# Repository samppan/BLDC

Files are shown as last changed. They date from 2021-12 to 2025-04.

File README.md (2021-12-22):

# BLDC

## BLDC Motor Driver Architecture
3 key building blocks for BLDC motor driver are: 
1. Motor controller, typically a MCU
2. Gate Drivers; PWM input, output drives half-bridges
3. Power MOSFET in half-bridges
4. Senseored feedback
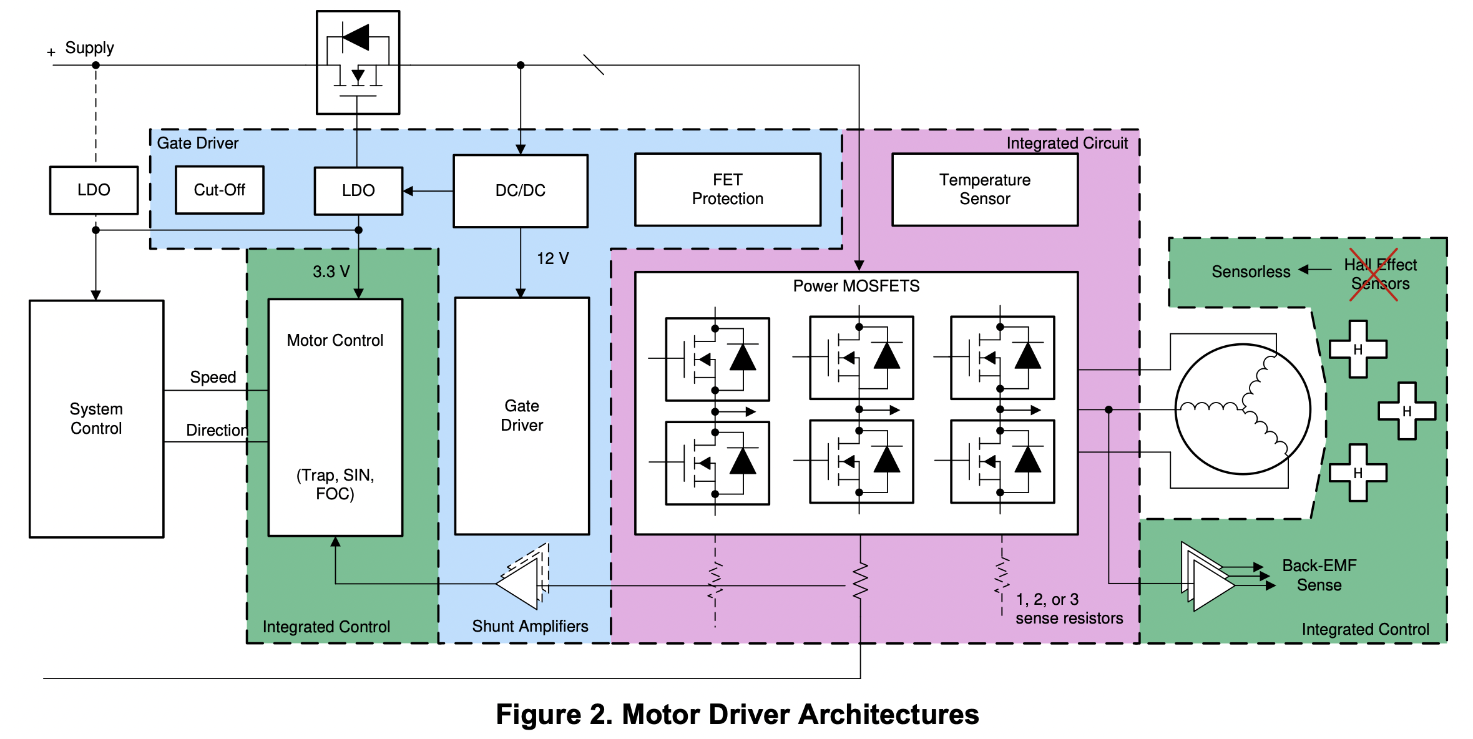
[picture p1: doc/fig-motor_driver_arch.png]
Source: TI

<figcaption>Source: TI</figcaption>

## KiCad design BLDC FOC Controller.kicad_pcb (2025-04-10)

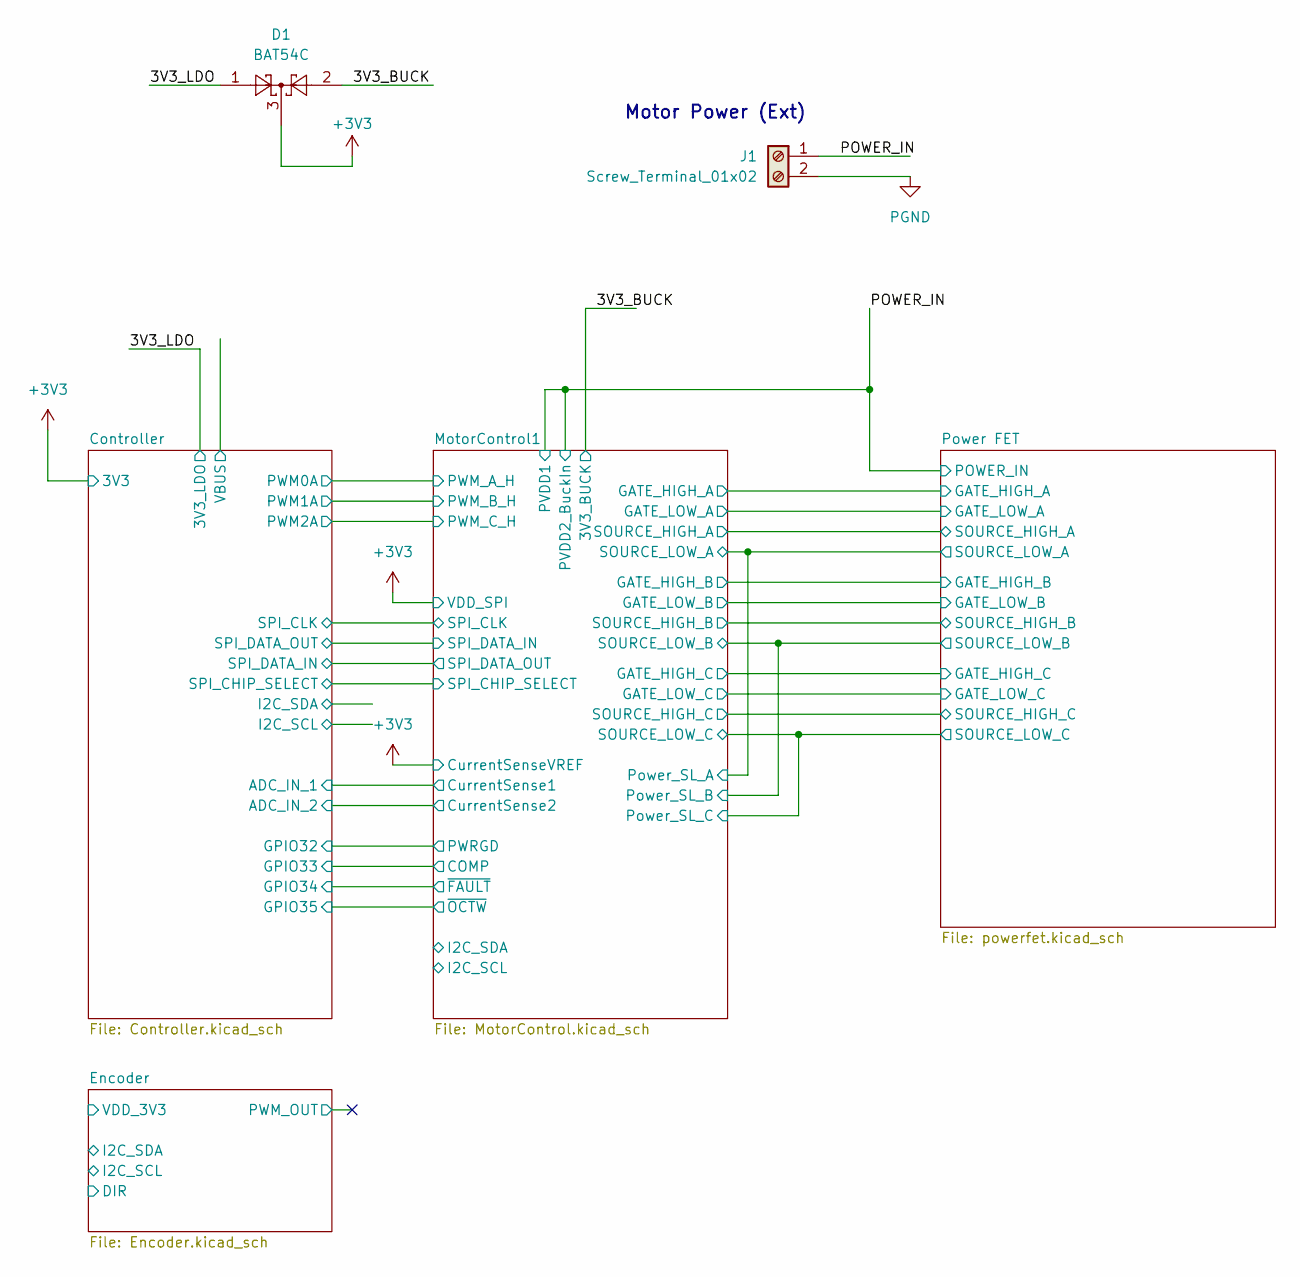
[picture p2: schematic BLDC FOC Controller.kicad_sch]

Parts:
D1: BAT54C; SOT-23
J1: Screw_Terminal_01x02; TerminalBlock_TE_282834-2_1x02_P2.54mm_Horizontal

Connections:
/3V3_BUCK: D1.2; also elsewhere on the board
/3V3_LDO: D1.1; also elsewhere on the board
/POWER_IN: J1.1; also elsewhere on the board
GNDA: J1.2; also elsewhere on the board

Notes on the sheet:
Motor Power (Ext)

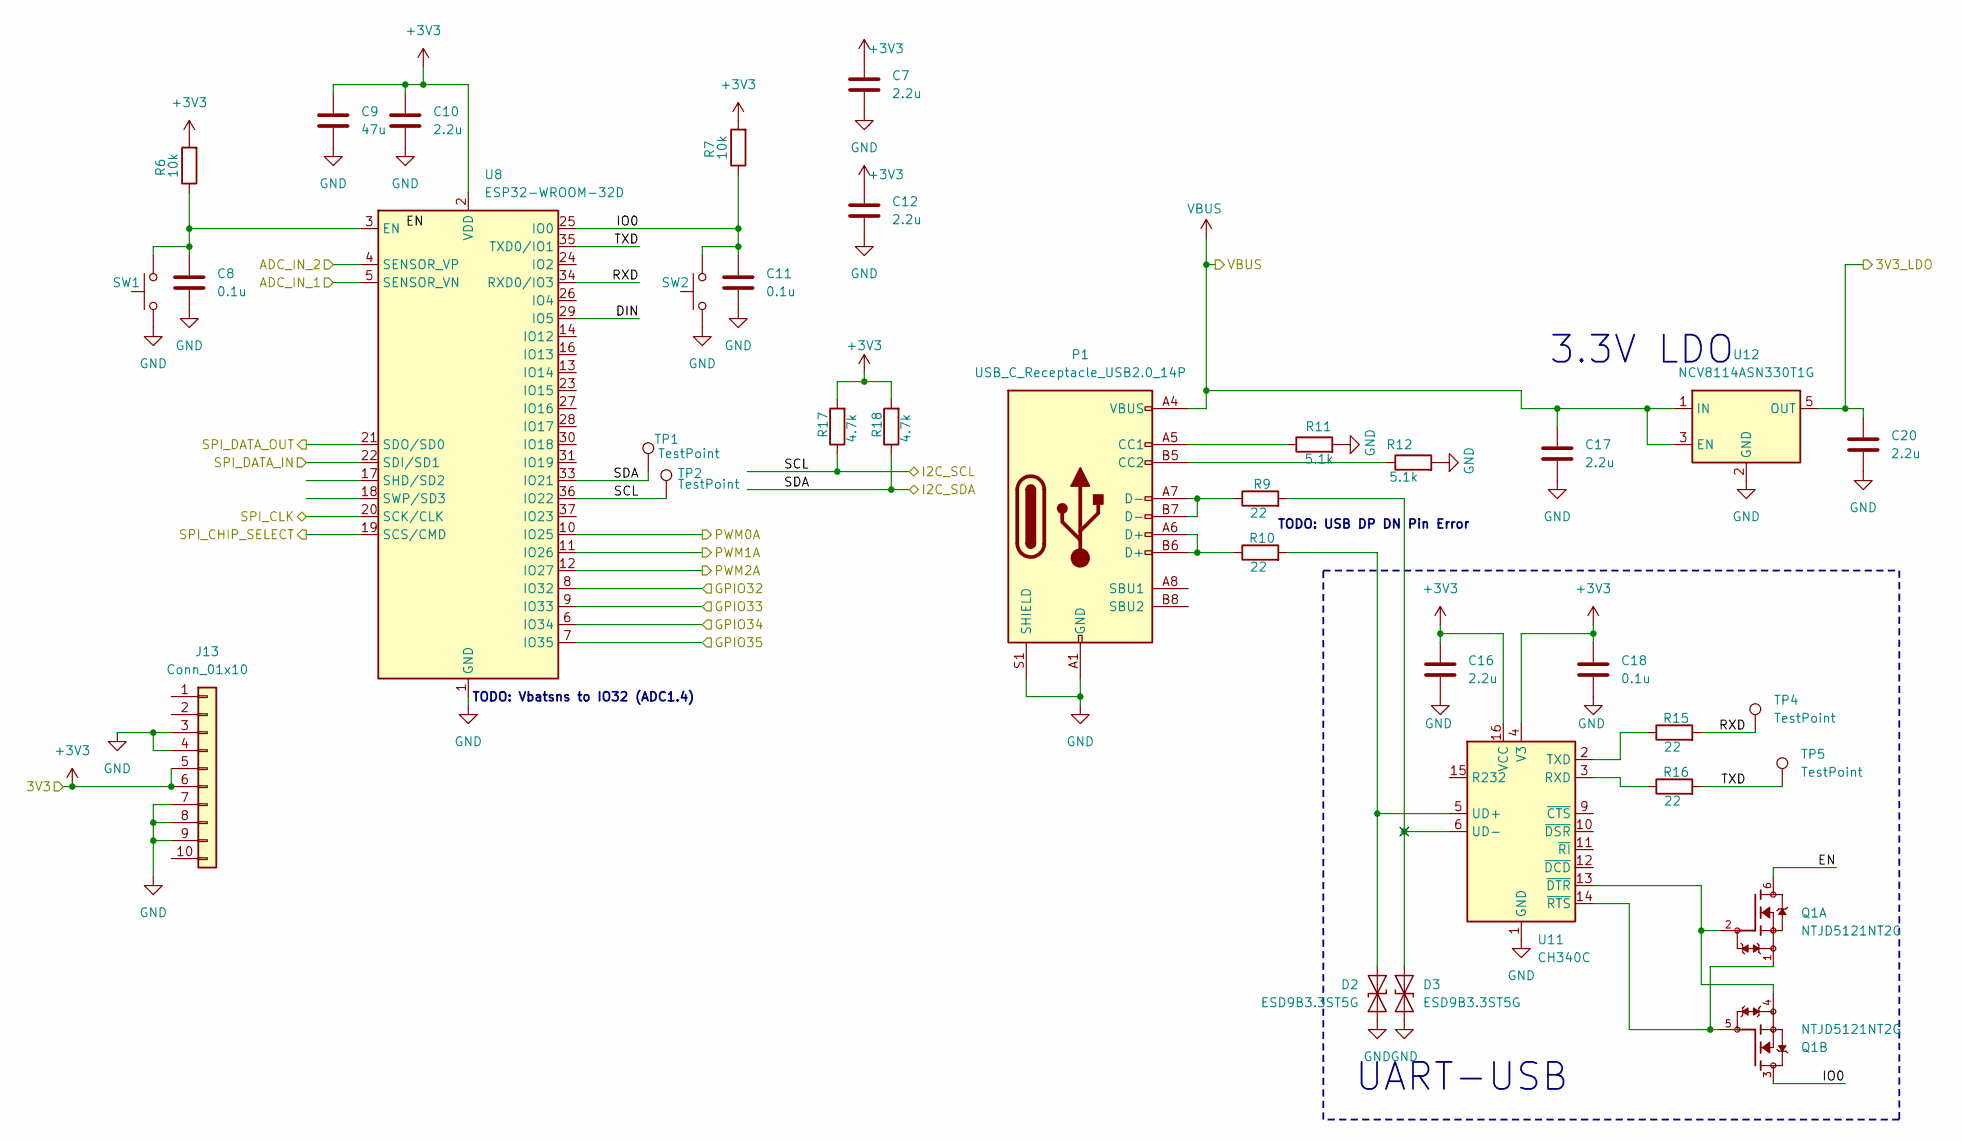
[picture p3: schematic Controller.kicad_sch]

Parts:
C7, C10, C12, C16, C17, C20: 2.2u; C_0603_1608Metric_Pad1.08x0.95mm_HandSolder
C8, C11, C18: 0.1u; C_0603_1608Metric_Pad1.08x0.95mm_HandSolder
C9: 47u; C_1206_3216Metric_Pad1.33x1.80mm_HandSolder
D2, D3: ESD9B3.3ST5G; D_SOD-923
J13: Conn_01x10; PinSocket_1x10_P2.54mm_Vertical
P1: USB_C_Receptacle_USB2.0_14P; USB_C_Receptacle_JAE_DX07S016JA1R1500
Q1: NTJD5121NT2G; SOT65P210X110-6N; PARTREV 9
R6, R7: 10k; R_0603_1608Metric_Pad0.98x0.95mm_HandSolder
R9, R10, R15, R16: 22; R_0603_1608Metric_Pad0.98x0.95mm_HandSolder
R11, R12: 5.1k; R_0603_1608Metric_Pad0.98x0.95mm_HandSolder
R17, R18: 4.7k; R_0603_1608Metric_Pad0.98x0.95mm_HandSolder
SW1, SW2: SW_Push_SPST_NO_Alps_SKRK
TP1, TP2, TP4, TP5: TestPoint; TestPoint_Pad_D1.5mm
U8: ESP32-WROOM-32D
U11: CH340C; SOIC-16_3.9x9.9mm_P1.27mm
U12: NCV8114ASN330T1G; TSOT-23-5

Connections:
/3V3_LDO: C20.1, U12.5 (OUT); also elsewhere on the board
/Controller/DIN: U8.29 (IO5)
/Controller/IO0: C11.1, Q1.3, R7.1, SW2.2, U8.25 (IO0)
/Controller/RXD: R15.2, TP4.1, U8.34 (RXD0/IO3)
/Controller/SCL: R17.1, TP2.1, U8.36 (IO22)
/Controller/SDA: R18.1, TP1.1, U8.33 (IO21)
/Controller/TXD: R16.2, TP5.1, U8.35 (TXD0/IO1)
/MotorControl1/COMP: U8.9 (IO33); also elsewhere on the board
/MotorControl1/INH_A: U8.10 (IO25); also elsewhere on the board
/MotorControl1/INH_B: U8.11 (IO26); also elsewhere on the board
/MotorControl1/INH_C: U8.12 (IO27); also elsewhere on the board
/MotorControl1/PWRGD: U8.8 (IO32); also elsewhere on the board
/MotorControl1/SCLK: U8.20 (SCK/CLK); also elsewhere on the board
/MotorControl1/SDI: U8.21 (SDO/SD0); also elsewhere on the board
/MotorControl1/SDO: U8.22 (SDI/SD1); also elsewhere on the board
/MotorControl1/SO1: U8.5 (SENSOR_VN); also elsewhere on the board
/MotorControl1/SO2: U8.4 (SENSOR_VP); also elsewhere on the board
/MotorControl1/~FAULT: U8.6 (IO34); also elsewhere on the board
/MotorControl1/~OCTW: U8.7 (IO35); also elsewhere on the board
/MotorControl1/~SCS: U8.19 (SCS/CMD); also elsewhere on the board
GND: C7.2, C8.2, C9.2, C10.2, C11.2, C12.2, C16.2, C17.2, C18.2, C20.2, D2.1 (A1), D3.1 (A1), J13.3, J13.4, J13.7, J13.8, J13.9, P1.A1 (GND), P1.A12 (GND), P1.B1 (GND), P1.B12 (GND), P1.S1 (SHIELD), R11.2, R12.2, SW1.1, SW2.1, U8.1 (GND), U8.15 (GND), U8.38 (GND), U8.39 (GND), U11.1 (GND), U12.2 (GND); also elsewhere on the board
unnamed: D2.2 (A2), R10.2, U11.5 (UD+)
unnamed: P1.A5 (CC1), R11.1
unnamed: P1.B5 (CC2), R12.1
unnamed: P1.A6 (D+), P1.B6 (D+), R10.1
unnamed: P1.A7 (D-), P1.B7 (D-), R9.1
unnamed: C8.1, R6.1, SW1.2, U8.3 (EN)
unnamed: R16.1, U11.3 (RXD)
unnamed: R15.1, U11.2 (TXD)
unnamed: Q1.2, Q1.4, U11.13 (~DTR)
unnamed: Q1.1, Q1.5, U11.14 (~RTS)
VBUS: C17.1, P1.A4 (VBUS), P1.A9 (VBUS), P1.B4 (VBUS), P1.B9 (VBUS), U12.1 (IN), U12.3 (EN)

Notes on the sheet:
UART-USB
3.3V LDO
TODO: Vbatsns to IO32 (ADC1.4)
TODO: USB DP DN Pin Error

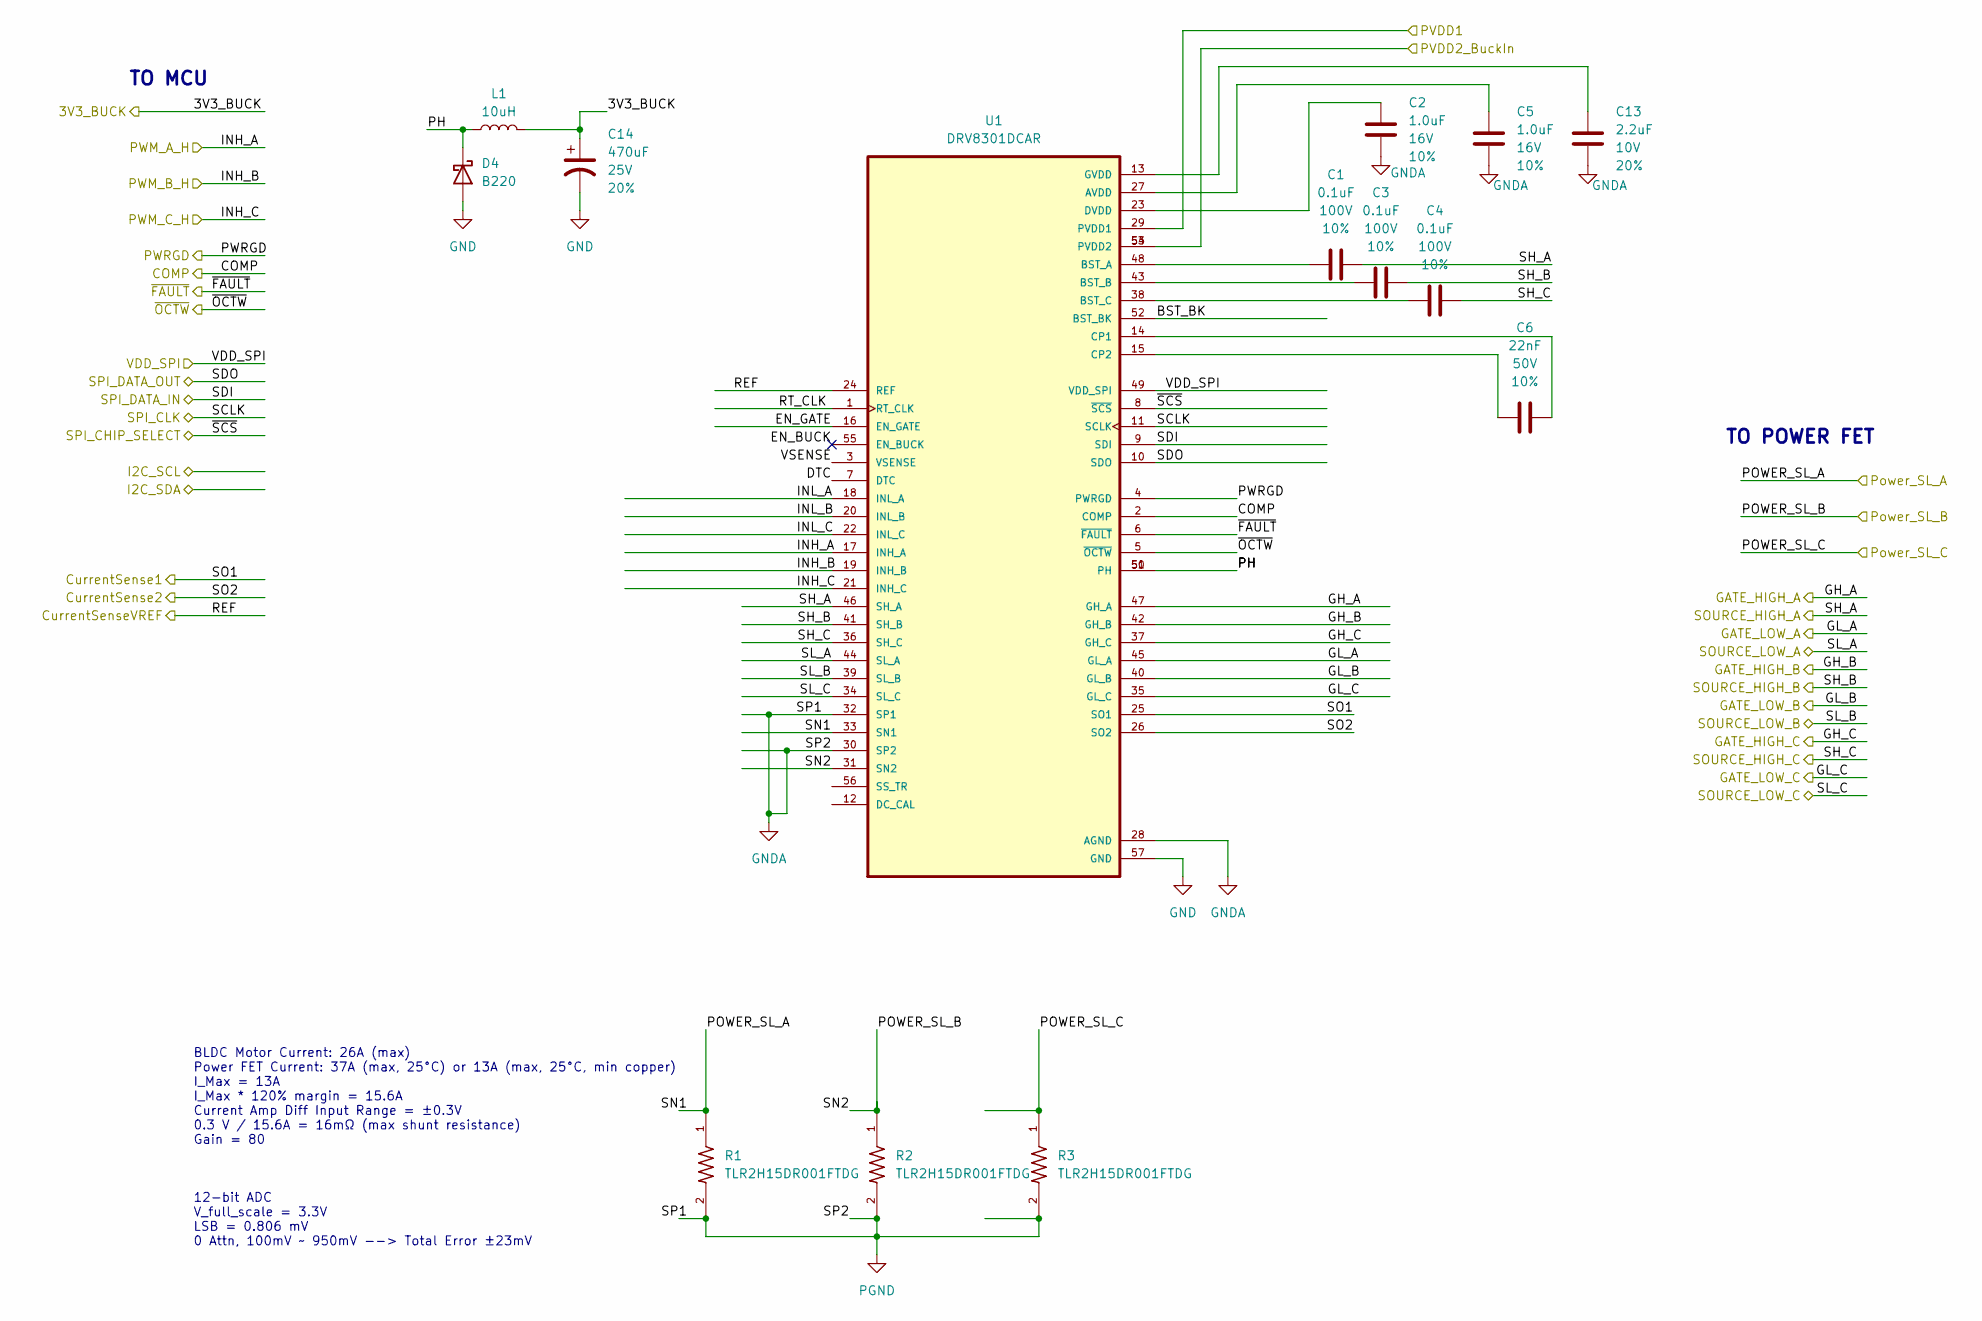
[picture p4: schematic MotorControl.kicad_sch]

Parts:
C1, C3, C4: 0.1uF; C_0603_1608Metric; Voltage 100V; Tolerance 10%
C2, C5: 1.0uF; C_0603_1608Metric; Voltage 16V; Tolerance 10%
C6: 22nF; C_0603_1608Metric; Voltage 50V; Tolerance 10%
C13: 2.2uF; C_0603_1608Metric_Pad1.08x0.95mm_HandSolder; Voltage 10V; Tolerance 20%
C14: 470uF; CP_Elec_10x10; Voltage 25V; Tolerance 20%
D4: B220; D_SMB
L1: 10uH; L_Taiyo-Yuden_NR-50xx_HandSoldering
R1, R2, R3: TLR2H15DR001FTDG; RESC5025X70N; Tolerance 1%
U1: DRV8301DCAR; HTSSOP-56-1EP_6.1x14mm_P0.5mm_EP3.61x6.35mm; PARTREV F

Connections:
/3V3_BUCK: C14.1, L1.2; also elsewhere on the board
/MotorControl1/BST_BK: U1.52 (BST_BK)
/MotorControl1/COMP: U1.2 (COMP); also elsewhere on the board
/MotorControl1/DTC: U1.7 (DTC)
/MotorControl1/EN_BUCK: U1.55 (EN_BUCK)
/MotorControl1/EN_GATE: U1.16 (EN_GATE)
/MotorControl1/GH_A: U1.47 (GH_A); also elsewhere on the board
/MotorControl1/GH_B: U1.42 (GH_B); also elsewhere on the board
/MotorControl1/GH_C: U1.37 (GH_C); also elsewhere on the board
/MotorControl1/GL_A: U1.45 (GL_A); also elsewhere on the board
/MotorControl1/GL_B: U1.40 (GL_B); also elsewhere on the board
/MotorControl1/GL_C: U1.35 (GL_C); also elsewhere on the board
/MotorControl1/INH_A: U1.17 (INH_A); also elsewhere on the board
/MotorControl1/INH_B: U1.19 (INH_B); also elsewhere on the board
/MotorControl1/INH_C: U1.21 (INH_C); also elsewhere on the board
/MotorControl1/INL_A: U1.18 (INL_A)
/MotorControl1/INL_B: U1.20 (INL_B)
/MotorControl1/INL_C: U1.22 (INL_C)
/MotorControl1/PH: D4.1 (K), L1.1, U1.50 (PH), U1.51 (PH)
/MotorControl1/POWER_SL_A: R1.1, U1.33 (SN1), U1.44 (SL_A); also elsewhere on the board
/MotorControl1/POWER_SL_C: R3.1, U1.34 (SL_C); also elsewhere on the board
/MotorControl1/PWRGD: U1.4 (PWRGD); also elsewhere on the board
/MotorControl1/RT_CLK: U1.1 (RT_CLK)
/MotorControl1/SCLK: U1.11 (SCLK); also elsewhere on the board
/MotorControl1/SDI: U1.9 (SDI); also elsewhere on the board
/MotorControl1/SDO: U1.10 (SDO); also elsewhere on the board
/MotorControl1/SH_A: C1.2, U1.46 (SH_A); also elsewhere on the board
/MotorControl1/SH_B: C3.2, U1.41 (SH_B); also elsewhere on the board
/MotorControl1/SH_C: C4.2, U1.36 (SH_C); also elsewhere on the board
/MotorControl1/SO1: U1.25 (SO1); also elsewhere on the board
/MotorControl1/SO2: U1.26 (SO2); also elsewhere on the board
/MotorControl1/VSENSE: U1.3 (VSENSE)
/MotorControl1/~FAULT: U1.6 (~FAULT); also elsewhere on the board
/MotorControl1/~OCTW: U1.5 (~OCTW); also elsewhere on the board
/MotorControl1/~SCS: U1.8 (~SCS); also elsewhere on the board
/POWER_IN: U1.29 (PVDD1), U1.53 (PVDD2), U1.54 (PVDD2); also elsewhere on the board
GND: C14.2, D4.2 (A), U1.57 (GND); also elsewhere on the board
GNDA: C2.2, C5.2, C13.2, R1.2, R2.2, R3.2, U1.28 (AGND), U1.30 (SP2), U1.32 (SP1); also elsewhere on the board
unnamed: C5.1, U1.27 (AVDD)
unnamed: C1.1, U1.48 (BST_A)
unnamed: C3.1, U1.43 (BST_B)
unnamed: C4.1, U1.38 (BST_C)
unnamed: C6.1, U1.14 (CP1)
unnamed: C6.2, U1.15 (CP2)
unnamed: C2.1, U1.23 (DVDD)
unnamed: C13.1, U1.13 (GVDD)

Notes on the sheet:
BLDC Motor Current: 26A (max) Power FET Current: 37A (max, 25°C) or 13A (max, 25°C, min copper) I_Max = 13A I_Max * 120% margin = 15.6A Current Amp Diff Input Range = ±0.3V 0.3 V / 15.6A = 16mΩ (max shunt resistance) Gain = 80 12-bit ADC V_full_scale = 3.3V LSB = 0.806 mV 0 Attn, 100mV ~ 950mV --> 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
TO MCU
TO POWER FET

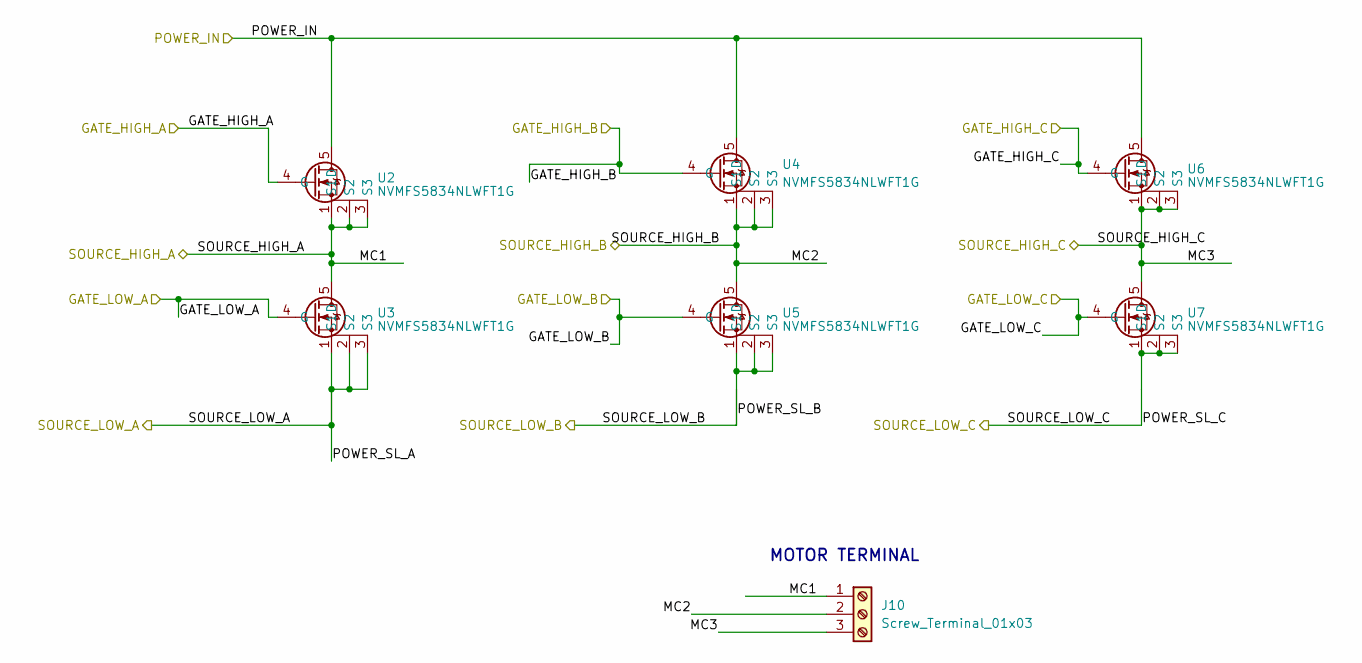
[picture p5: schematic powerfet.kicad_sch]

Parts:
J10: Screw_Terminal_01x03; TerminalBlock_TE_282834-3_1x03_P2.54mm_Horizontal
U2, U3, U4, U5, U6, U7: NVMFS5834NLWFT1G; TRANS_NVMFS5834NLWFT1G

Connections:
/MotorControl1/GH_A: U2.4 (G); also elsewhere on the board
/MotorControl1/GH_B: U4.4 (G); also elsewhere on the board
/MotorControl1/GH_C: U6.4 (G); also elsewhere on the board
/MotorControl1/GL_A: U3.4 (G); also elsewhere on the board
/MotorControl1/GL_B: U5.4 (G); also elsewhere on the board
/MotorControl1/GL_C: U7.4 (G); also elsewhere on the board
/MotorControl1/POWER_SL_A: U3.1 (S1), U3.2 (S2), U3.3 (S3); also elsewhere on the board
/MotorControl1/POWER_SL_C: U7.1 (S1), U7.2 (S2), U7.3 (S3); also elsewhere on the board
/MotorControl1/SH_A: J10.1, U2.1 (S1), U2.2 (S2), U2.3 (S3), U3.5 (D); also elsewhere on the board
/MotorControl1/SH_B: J10.2, U4.1 (S1), U4.2 (S2), U4.3 (S3), U5.5 (D); also elsewhere on the board
/MotorControl1/SH_C: J10.3, U6.1 (S1), U6.2 (S2), U6.3 (S3), U7.5 (D); also elsewhere on the board
/POWER_IN: U2.5 (D), U4.5 (D), U6.5 (D); also elsewhere on the board

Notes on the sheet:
MOTOR TERMINAL

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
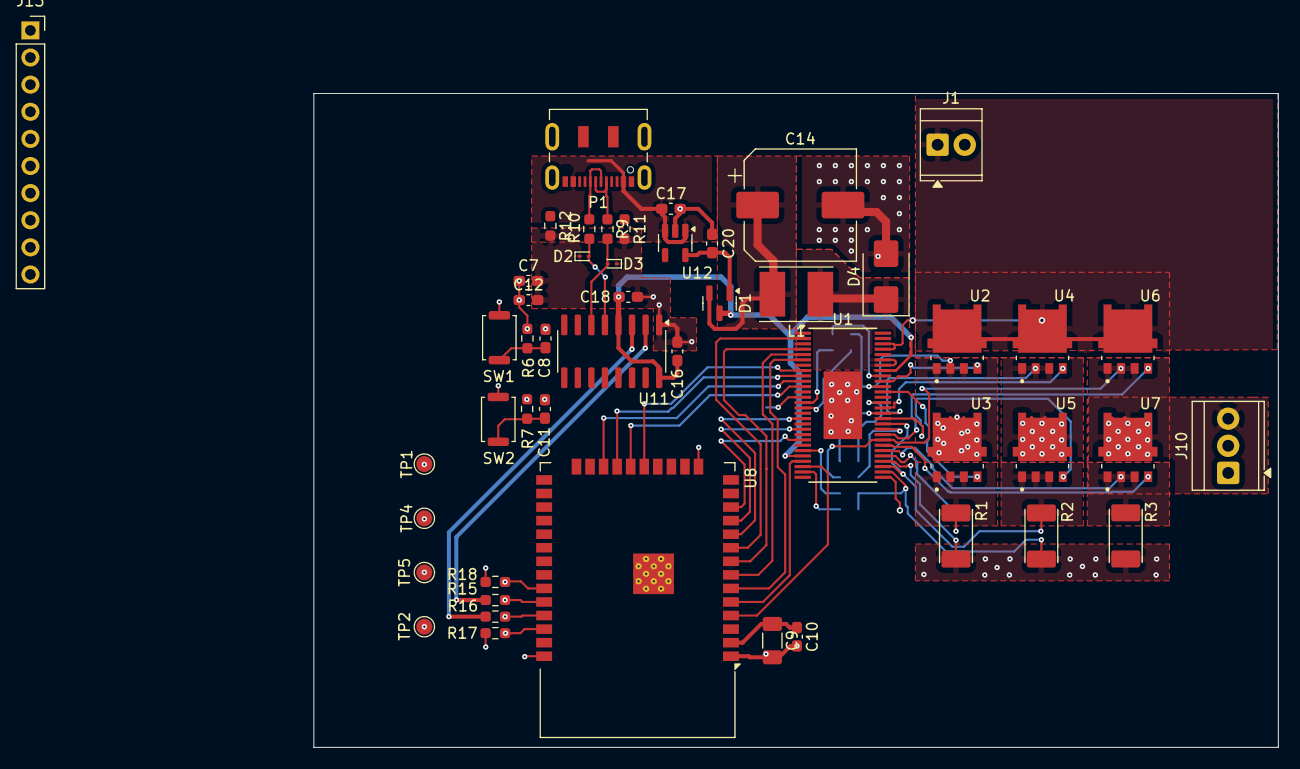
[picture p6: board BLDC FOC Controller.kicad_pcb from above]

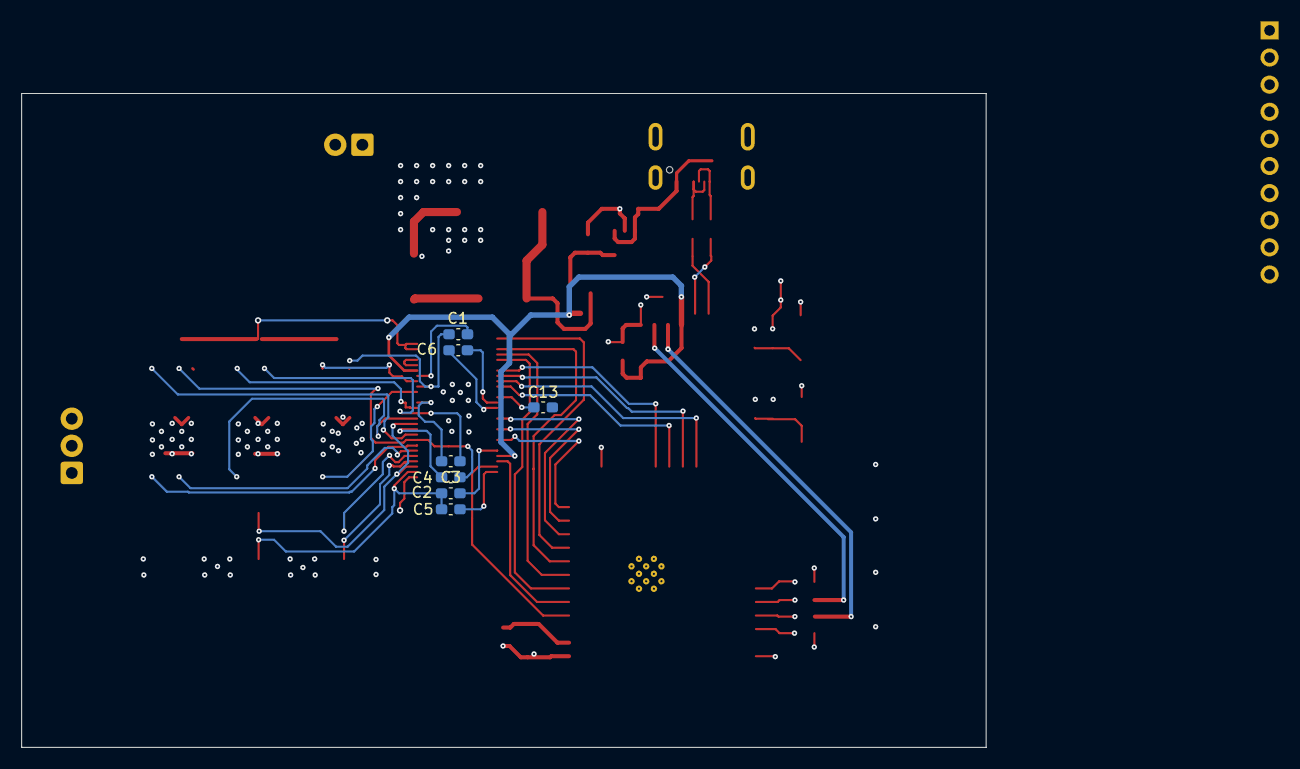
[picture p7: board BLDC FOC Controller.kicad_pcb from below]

Board: 4 copper layers, 90.3 x 61.2 mm, 56 parts (7 on the bottom side), 54 nets.
